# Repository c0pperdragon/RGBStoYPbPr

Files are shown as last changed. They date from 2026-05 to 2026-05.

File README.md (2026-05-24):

# RGBStoYPbPr

A fairly simple video converter from RGBS to YPbPr. My main challenge here is to make it work with only stuff that I have incidentially at home.
 
The PCB is a small single-sided leftover piece that was just big enough to fit the circuitry. Home etching, using the well-known toner transfer method,
turned out pretty nicely. To create the necessary non-standard resistor values, I soldered several resistors on top of each other. 
When allowing up to three resistors in a parallel configuration, the computer search finds an extremly good fit for every desired value
by using only the E6 series.

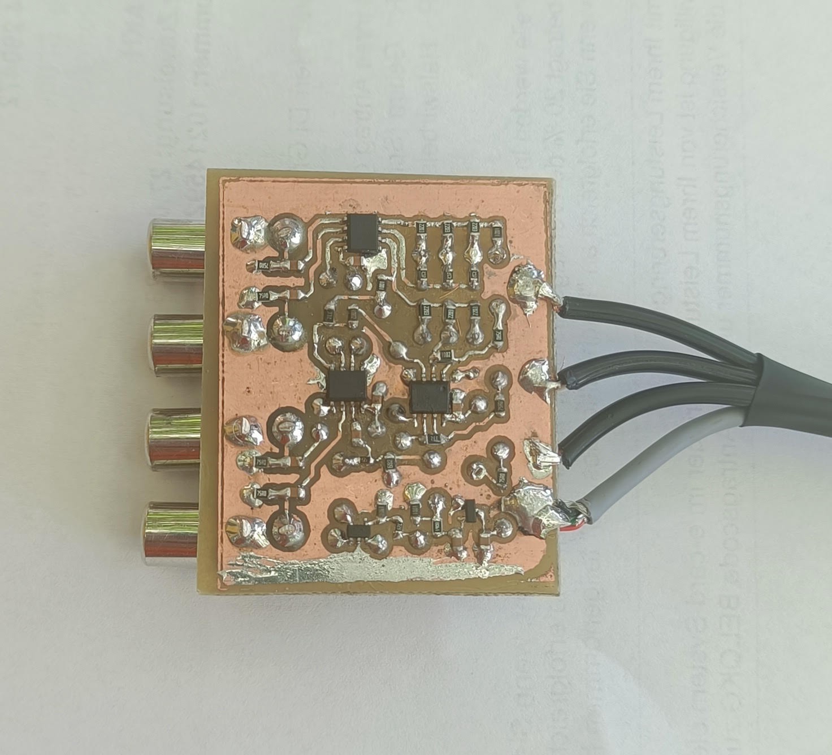
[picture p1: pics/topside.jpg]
Single sided PCB with components

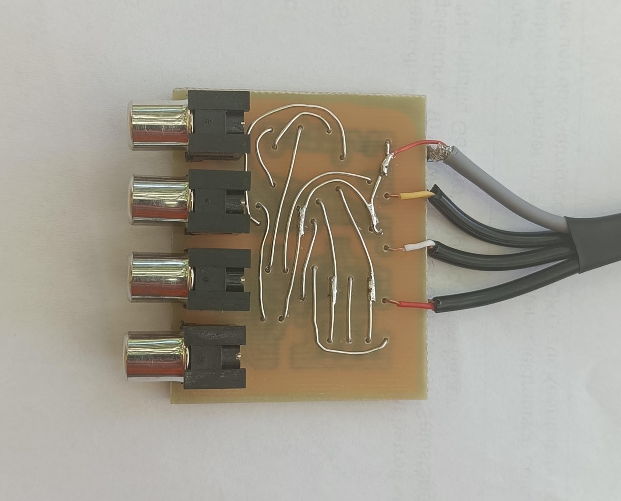
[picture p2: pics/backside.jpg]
Back side wiring


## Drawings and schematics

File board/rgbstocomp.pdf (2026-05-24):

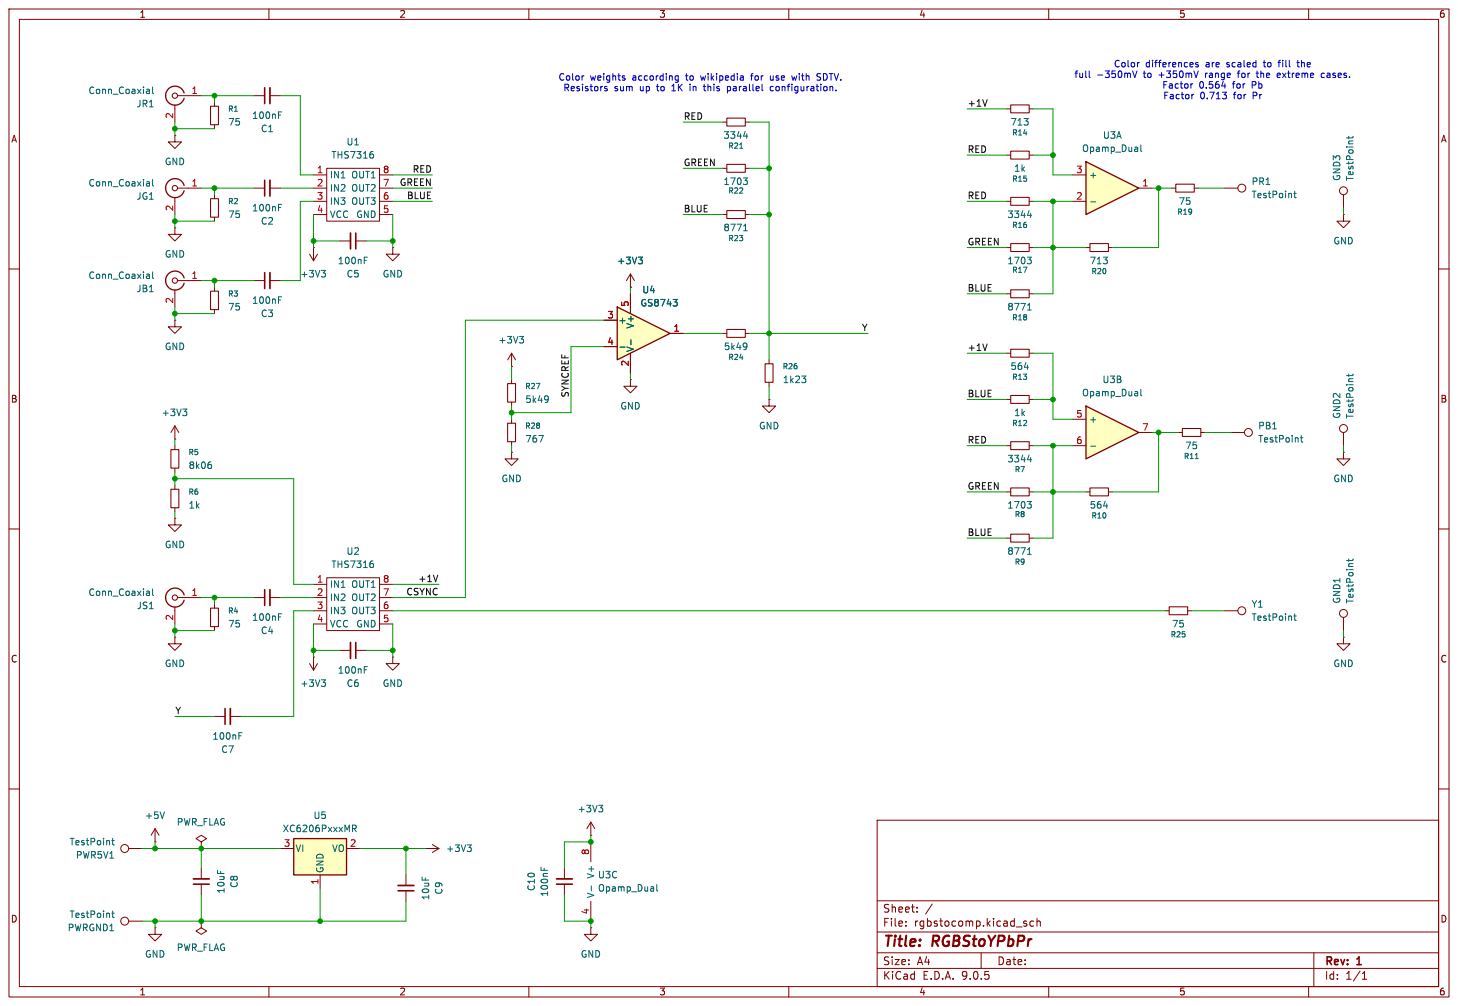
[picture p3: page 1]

Id: 1/1 Title: RGBStoYPbPr File: rgbstocomp.kicad_sch Sheet: / C6

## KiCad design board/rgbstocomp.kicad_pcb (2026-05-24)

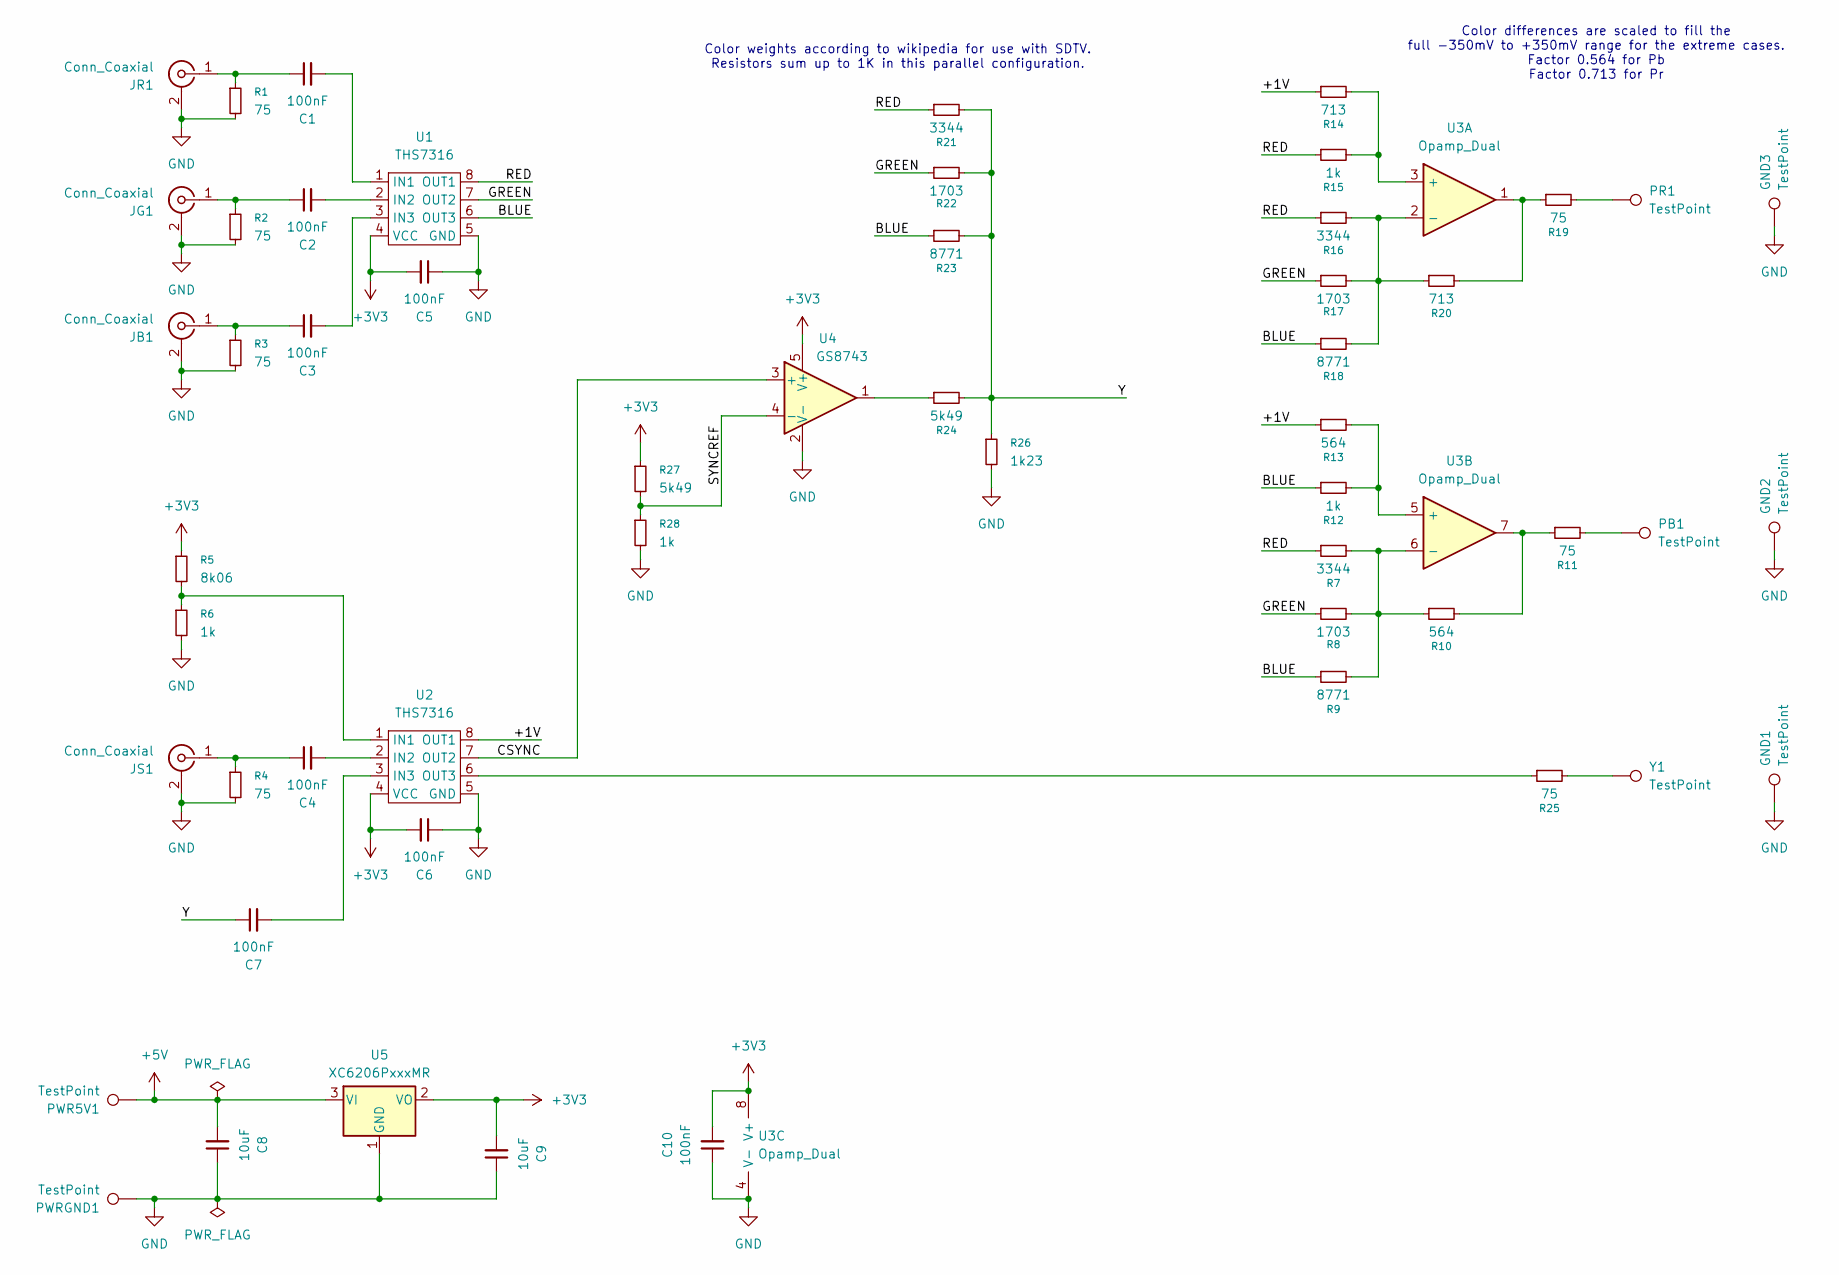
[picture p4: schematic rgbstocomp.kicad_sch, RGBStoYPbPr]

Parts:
C1, C2, C3, C4, C5, C6, C7, C10: 100nF; C_0805_2012Metric_Pad1.18x1.45mm_HandSolder
C8, C9: 10uF; C_0805_2012Metric_Pad1.18x1.45mm_HandSolder
GND1, GND2, GND3: TestPoint; TestPoint_Pad_3.0x3.0mm
JB1: Conn_Coaxial; 156-0097-E
JG1: Conn_Coaxial; 156-0097-E
JR1: Conn_Coaxial; 156-0097-E
JS1: Conn_Coaxial; 156-0097-E
PB1: TestPoint; TestPoint_Pad_3.0x3.0mm
PR1: TestPoint; TestPoint_Pad_3.0x3.0mm
PWR5V1: TestPoint; TestPoint_Pad_3.0x3.0mm
PWRGND1: TestPoint; TestPoint_Pad_3.0x3.0mm
R1, R2, R3, R4, R11, R19, R25: 75; R_0805_2012Metric_Pad1.20x1.40mm_HandSolder
R5: 8k06; R_0805_2012Metric_Pad1.20x1.40mm_HandSolder
R6, R12, R15, R28: 1k; R_0805_2012Metric_Pad1.20x1.40mm_HandSolder
R7, R16, R21: 3344; R_0805_2012Metric_Pad1.20x1.40mm_HandSolder
R8, R17, R22: 1703; R_0805_2012Metric_Pad1.20x1.40mm_HandSolder
R9, R18, R23: 8771; R_0805_2012Metric_Pad1.20x1.40mm_HandSolder
R10, R13: 564; R_0805_2012Metric_Pad1.20x1.40mm_HandSolder
R14, R20: 713; R_0805_2012Metric_Pad1.20x1.40mm_HandSolder
R24, R27: 5k49; R_0805_2012Metric_Pad1.20x1.40mm_HandSolder
R26: 1k23; R_0805_2012Metric_Pad1.20x1.40mm_HandSolder
U1, U2: THS7316; SO-8_3.9x4.9mm_P1.27mm
U3: Opamp_Dual; SO-8_3.9x4.9mm_P1.27mm
U4: GS8743; SOT-23-5
U5: XC6206PxxxMR; SOT-23-3
Y1: TestPoint; TestPoint_Pad_3.0x3.0mm

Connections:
+3V3: C5.2, C6.2, C9.2, C10.2, R5.1, R27.1, U1.4 (VCC), U2.4 (VCC), U3.8 (V+), U4.5 (V+), U5.2 (VO)
+5V: C8.2, PWR5V1.1, U5.3 (VI)
/+1V: R13.1, R14.1, U2.8 (OUT1)
/BLUE: R9.1, R12.1, R18.1, R23.1, U1.6 (OUT3)
/CSYNC: U2.7 (OUT2), U4.3 (+)
/GREEN: R8.1, R17.1, R22.1, U1.7 (OUT2)
/RED: R7.1, R15.1, R16.1, R21.1, U1.8 (OUT1)
/SYNCREF: R27.2, R28.1, U4.4 (-)
/Y: C7.1, R21.2, R22.2, R23.2, R24.2, R26.1
GND: C5.1, C6.1, C8.1, C9.1, C10.1, GND1.1, GND2.1, GND3.1, JB1.2 (Ext), JG1.2 (Ext), JR1.2 (Ext), JS1.2 (Ext), PWRGND1.1, R1.2, R2.2, R3.2, R4.2, R6.2, R26.2, R28.2, U1.5 (GND), U2.5 (GND), U3.4 (V-), U4.2 (V-), U5.1 (GND)
unnamed: C3.1, JB1.1 (In), R3.1
unnamed: C2.1, JG1.1 (In), R2.1
unnamed: C1.1, JR1.1 (In), R1.1
unnamed: C4.1, JS1.1 (In), R4.1
unnamed: PB1.1, R11.2
unnamed: PR1.1, R19.2
unnamed: R10.2, R11.1, U3.7
unnamed: R19.1, R20.2, U3.1
unnamed: R24.1, U4.1
unnamed: R25.2, Y1.1
unnamed: C1.2, U1.1 (IN1)
unnamed: C2.2, U1.2 (IN2)
unnamed: C3.2, U1.3 (IN3)
unnamed: R5.2, R6.1, U2.1 (IN1)
unnamed: C4.2, U2.2 (IN2)
unnamed: C7.2, U2.3 (IN3)
unnamed: R25.1, U2.6 (OUT3)
unnamed: R14.2, R15.2, U3.3 (+)
unnamed: R16.2, R17.2, R18.2, R20.1, U3.2 (-)
unnamed: R12.2, R13.2, U3.5 (+)
unnamed: R7.2, R8.2, R9.2, R10.1, U3.6 (-)

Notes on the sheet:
Color differences are scaled to fill the full -350mV to +350mV range for the extreme cases. Factor 0.564 for Pb Factor 0.713 for Pr
Color weights according to wikipedia for use with SDTV. Resistors sum up to 1K in this parallel configuration.

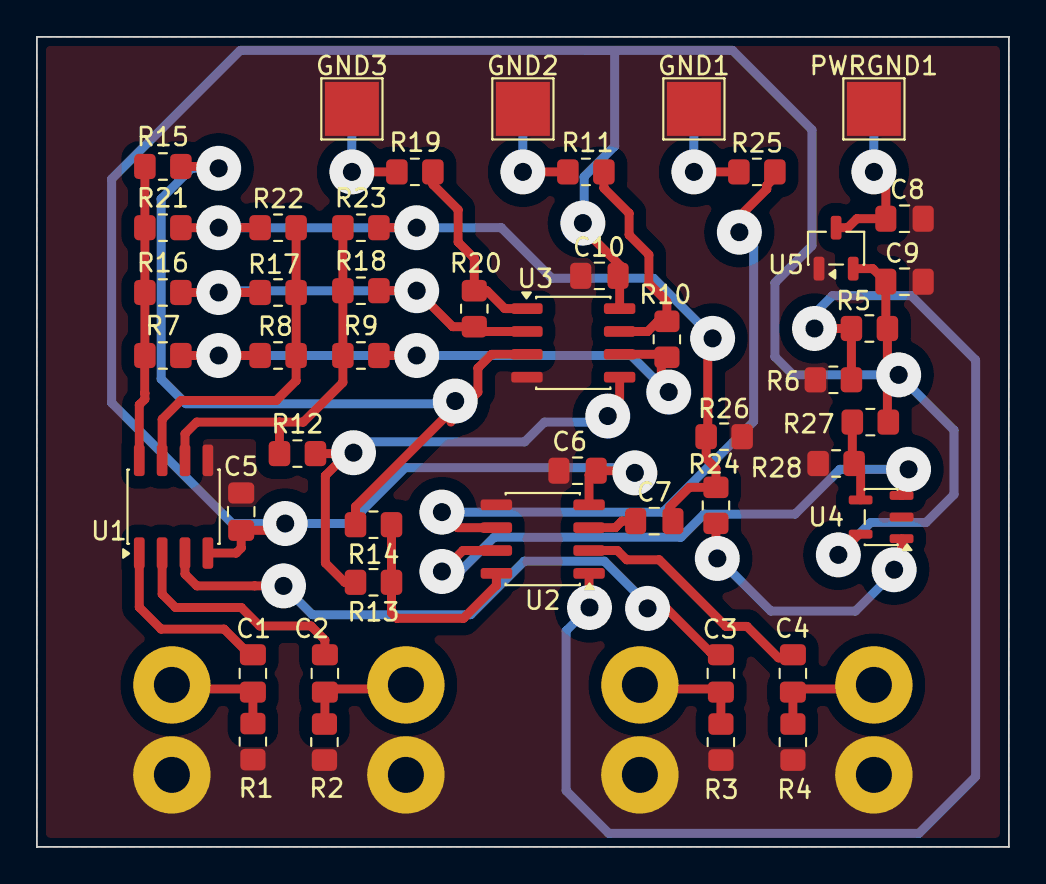
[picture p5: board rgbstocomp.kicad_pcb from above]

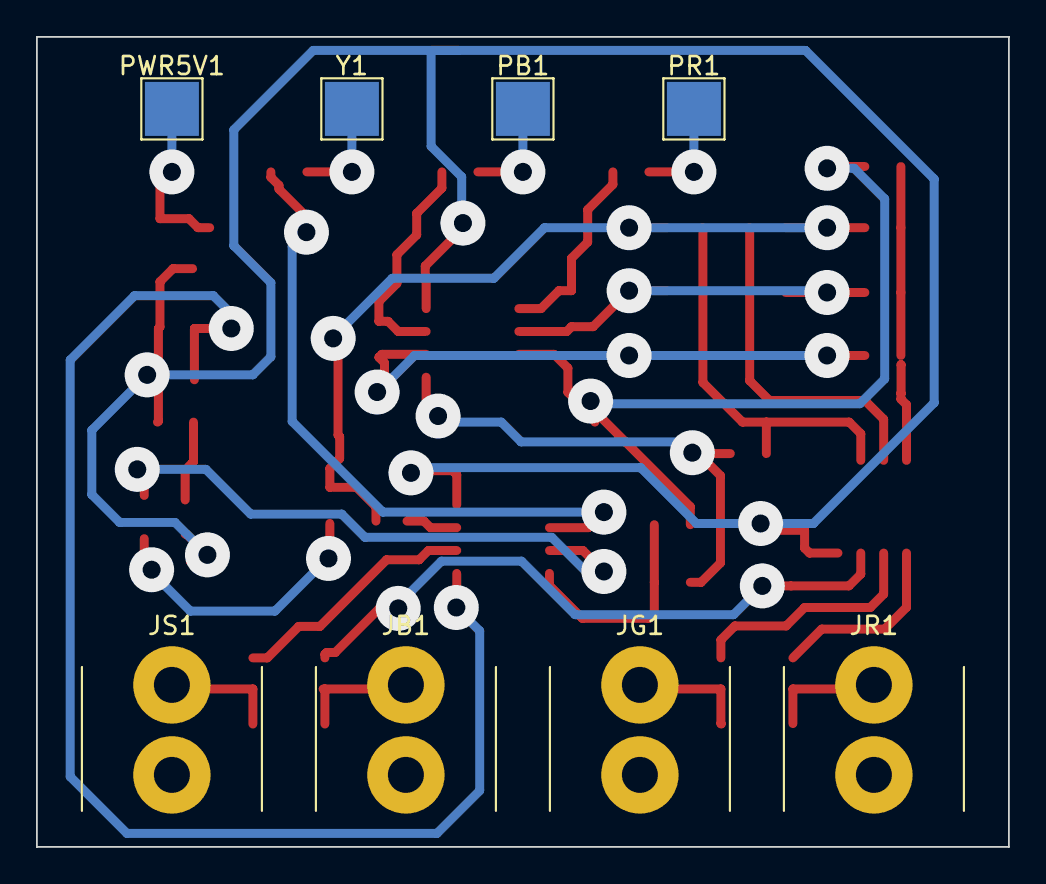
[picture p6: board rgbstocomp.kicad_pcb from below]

Board: 2 copper layers, 54.0 x 45.0 mm, 55 parts (8 on the bottom side), 31 nets.

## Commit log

2026-05-20 First schematic
    [resistors.ods, rgbstocomp.kicad_pcb, rgbstocomp.kicad_sch]
2026-05-21 PCB design
    [resistors.ods, rgbstocomp.kicad_pcb, rgbstocomp.kicad_sch]
2026-05-21 Fix CSYNC detection threashold
    [resistors.ods, rgbstocomp.kicad_pcb, rgbstocomp.kicad_sch]
2026-05-24 Supply ICs with 3.3V instead of with 5V. Add documentation.
    [resistors.ods, rgbstocomp.kicad_pcb, rgbstocomp.kicad_sch]
2026-05-24 Change resistor to create the csync reference voltage
    [rgbstocomp.kicad_sch]
